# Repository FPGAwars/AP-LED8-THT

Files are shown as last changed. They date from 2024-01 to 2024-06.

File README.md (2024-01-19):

# AP-LED8-THT
Alhambra Peripheral board with 8 through-hole LEDs

It is a tiny board with eight 3mm though-hole LEDs for connecting to the Alhambra-II FPGA board.  
This board is also used as a reference for teaching students how to design their first PCB (so, it is a kind of "hello world" hardware)

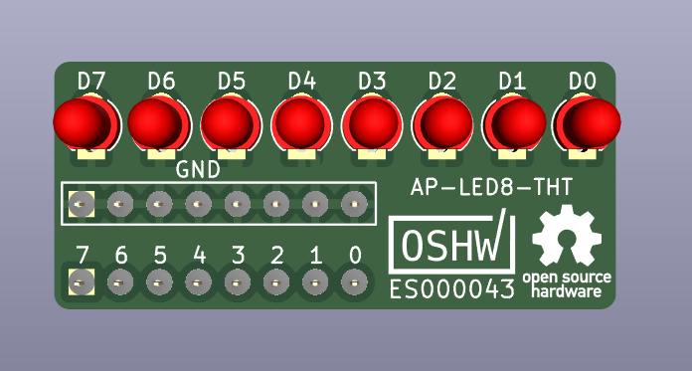
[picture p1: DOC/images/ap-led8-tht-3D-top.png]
Top view
  
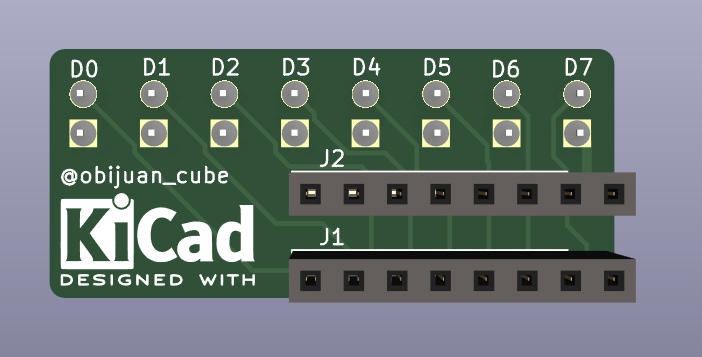
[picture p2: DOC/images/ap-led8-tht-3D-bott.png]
Bottom view
  
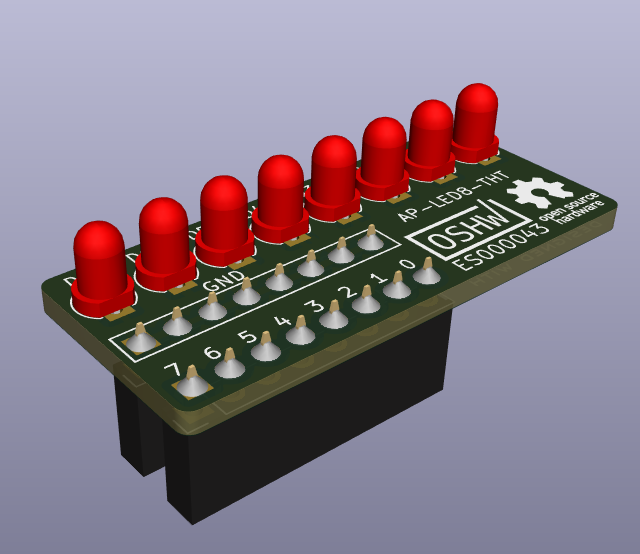
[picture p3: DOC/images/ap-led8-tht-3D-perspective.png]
Perspective View
  

## Connection to Alhambra II Board

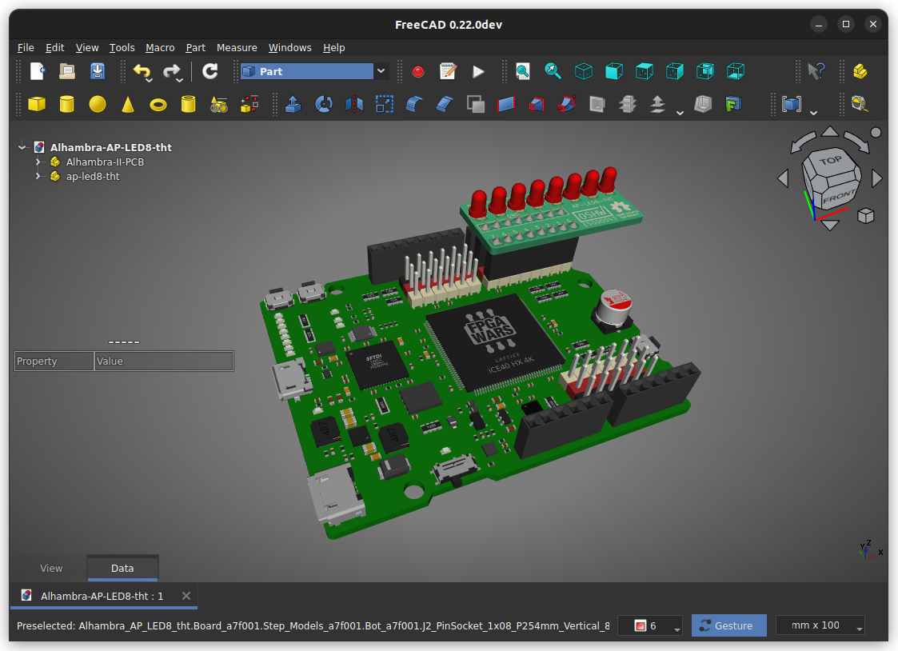
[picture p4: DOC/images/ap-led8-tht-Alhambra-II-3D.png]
Alhambra-II+AP-LED8-THT


## Certification mark

This board is Opensource hardware, certified by the [OSHWA](https://www.oshwa.org/)

* Certification ID: [ES000043](https://certification.oshwa.org/es000043.html)  

* Certification mark:



## License

Documentation licensed under the [Creative Commons Attribution Share Alike 4.0 International License](https://creativecommons.org/licenses/by-sa/4.0/)  


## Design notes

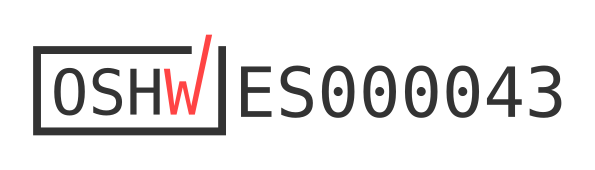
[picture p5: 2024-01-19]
DOC/OSHWA-certification/certification-mark-ES000043-wide.png

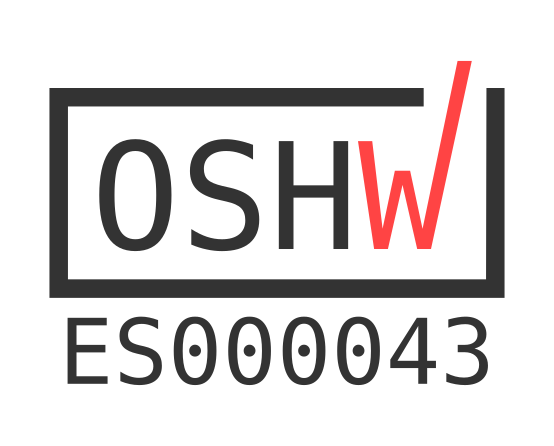
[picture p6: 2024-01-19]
DOC/OSHWA-certification/Certification-mark-ES000043-stacked.png

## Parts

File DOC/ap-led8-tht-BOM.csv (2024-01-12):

Source: | /home/obijuan/Develop/AP-LED8-THT/ap-led8-tht.kicad_sch
Date: | vie 12 ene 2024 10:51:23
Tool: | Eeschema 7.0.10-7.0.10~ubuntu22.04.1
Generator: | /usr/share/kicad/plugins/bom_csv_grouped_by_value.py
Component Count: | 10
Collated Components:
Item | Qty | Reference(s) | Value | LibPart | Footprint | Datasheet | DNP
1 | 8 | D0, D1, D2, D3, D4, D5, D6, D7 | LED | Device:LED | Monolito:LED_THT__LED_D3.0mm | ~
2 | 2 | J1, J2 | Conn_01x08_Socket | Connector:Conn_01x08_Socket | Monolito:PinSocket_1x08_P2.54mm_Vertical | ~

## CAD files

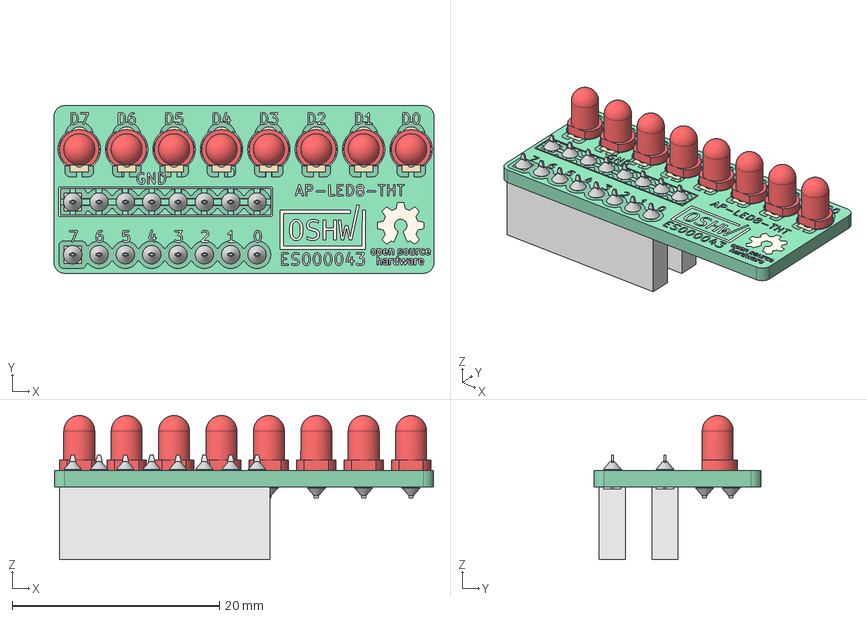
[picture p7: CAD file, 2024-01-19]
DOC/3D/AP-LED8-THT.FCStd
36.6 x 16.2 x 13.9 mm
Pcb_a7f0
topPads_a7f0
topTracks_a7f0
topZones_a7f0
botPads_a7f0
botTracks_a7f0
botSilks_889f
topSilks_854b001
LED-head x 8
Pin-master x 8
Pin-master001 x 8
Solder x 8
Solder001 x 8
J2_PinSocket_1x08_P254mm_Vertical_845b5e165b4b x 2
Solder002 x 2
Solder003 x 2
Solder004 x 2
Solder005 x 2
Solder006 x 2
Solder007 x 2
Solder008 x 2
Solder009 x 2

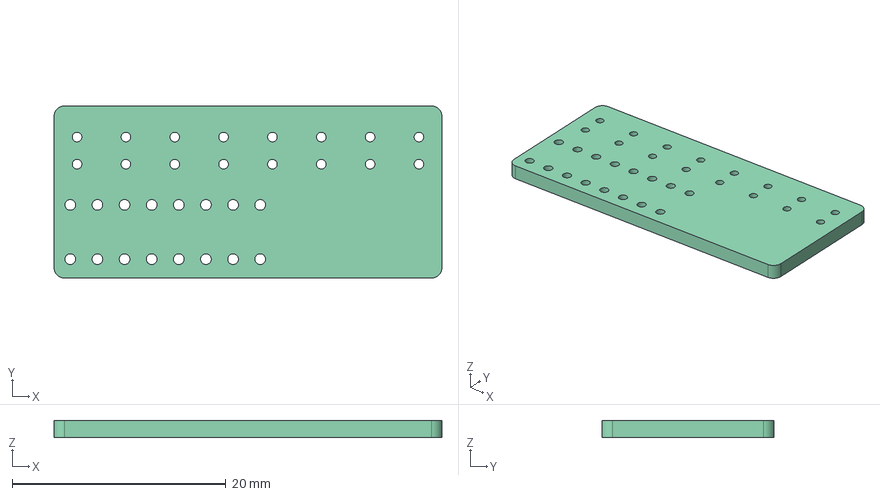
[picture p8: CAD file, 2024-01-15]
edge.FCStd
36.3 x 16.1 x 1.60 mm

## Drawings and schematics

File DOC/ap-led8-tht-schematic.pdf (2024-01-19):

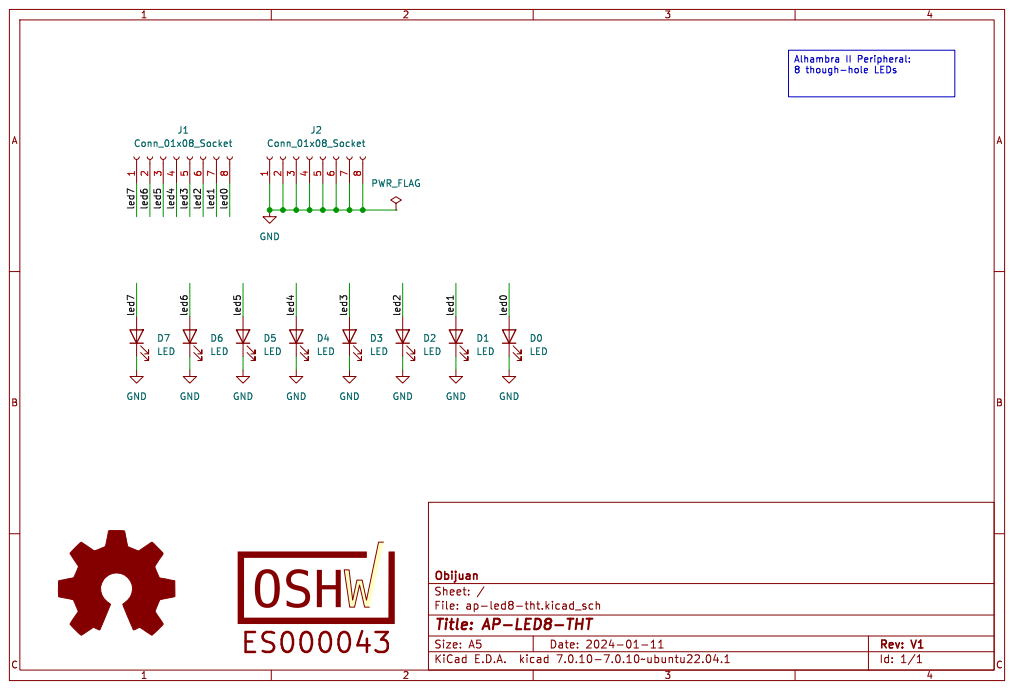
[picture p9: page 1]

File: ap-led8-tht.kicad_sch Sheet: / Obijuan D5

Id: 1/1 Title: AP-LED8-THT

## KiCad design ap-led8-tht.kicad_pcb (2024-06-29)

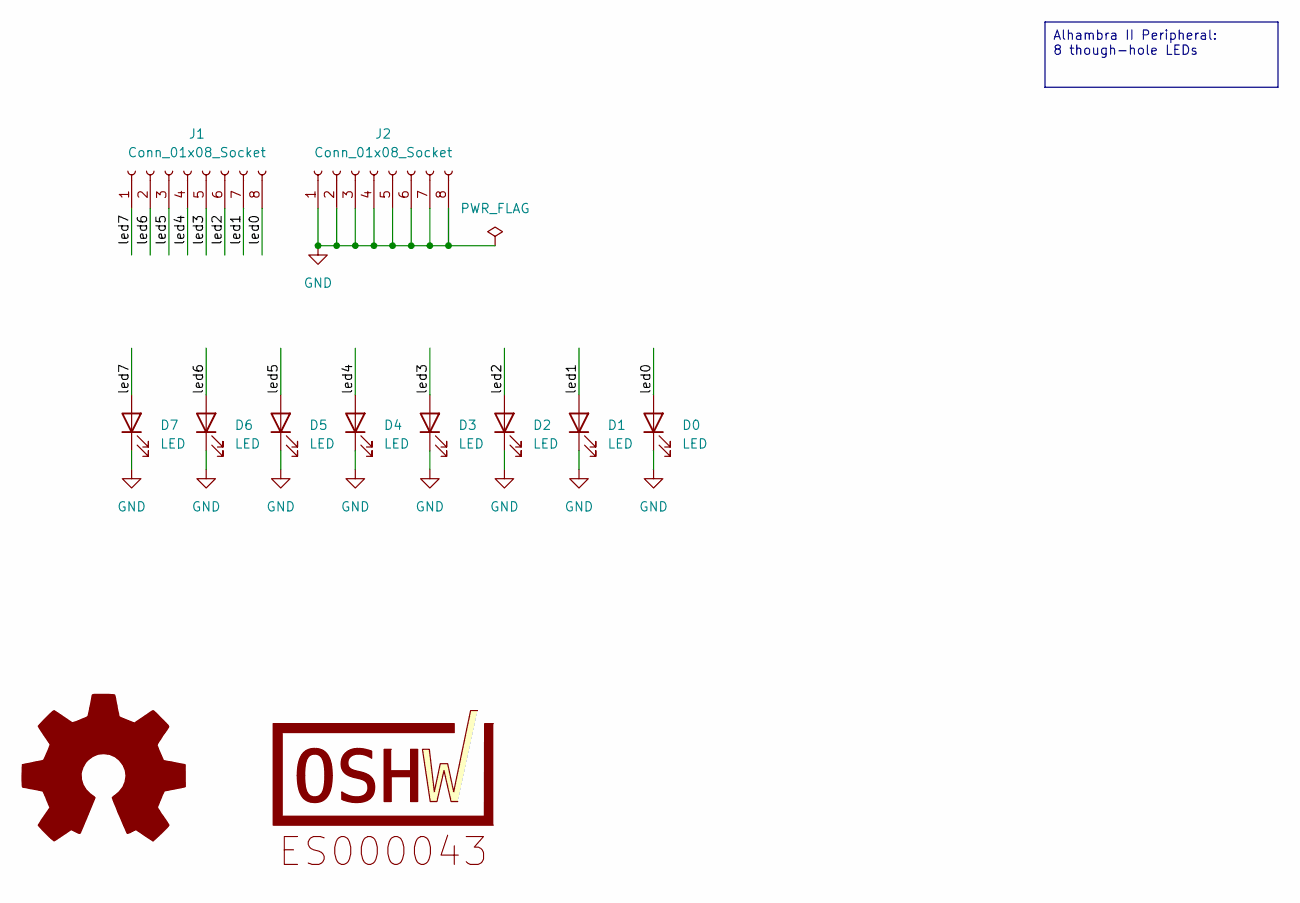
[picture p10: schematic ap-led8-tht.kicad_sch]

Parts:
D0, D1, D2, D3, D4, D5, D6, D7: LED; LED_THT__LED_D3.0mm
J1, J2: Conn_01x08_Socket; PinSocket_1x08_P2.54mm_Vertical
LOGO2: (no value)

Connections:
/led0: D0.2 (A), J1.8
/led1: D1.2 (A), J1.7
/led2: D2.2 (A), J1.6
/led3: D3.2 (A), J1.5
/led4: D4.2 (A), J1.4
/led5: D5.2 (A), J1.3
/led6: D6.2 (A), J1.2
/led7: D7.2 (A), J1.1
GND: D0.1 (K), D1.1 (K), D2.1 (K), D3.1 (K), D4.1 (K), D5.1 (K), D6.1 (K), D7.1 (K), J2.1, J2.2, J2.3, J2.4, J2.5, J2.6, J2.7, J2.8

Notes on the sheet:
Alhambra II Peripheral: 8 though-hole LEDs

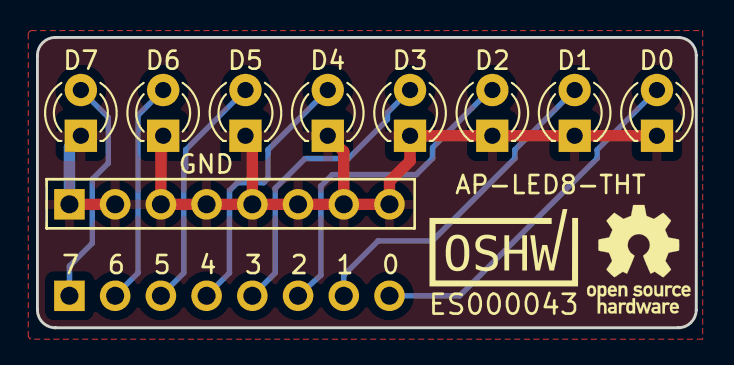
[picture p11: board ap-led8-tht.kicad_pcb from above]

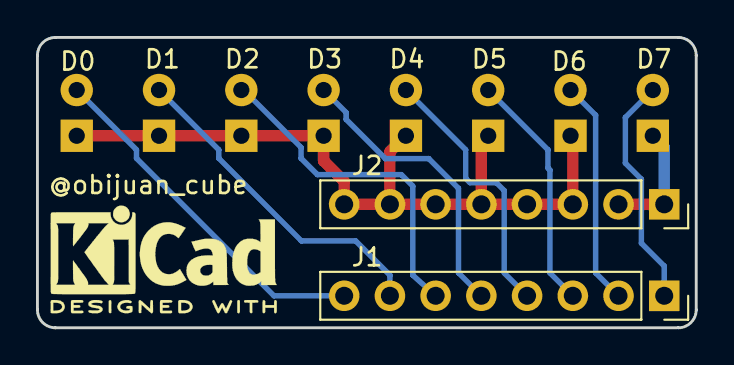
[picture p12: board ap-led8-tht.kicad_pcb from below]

Board: 2 copper layers, 36.6 x 16.1 mm, 10 parts (2 on the bottom side), 9 nets.

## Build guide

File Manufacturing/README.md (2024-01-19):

# Manufacturing

## 1st Batch

* Manufacturer: pcbway.com
* Quantity: 20 boards
* Price: 50€ aprox, including delivery (from china to Madrid, Spain)
* Date: 2024-Jan-19 (order placed)
* File sent: ap-led8-tht.kicad_pcb.zip. File automatically created with the Kicad pcbway plugin

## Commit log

2024-01-11 add initial design
    [ap-led8-tht.kicad_pcb, ap-led8-tht.kicad_sch]
2024-01-11 add monolito footprints and 3dshapes
2024-01-11 Initial PCB
    [ap-led8-tht.kicad_pcb, ap-led8-tht.kicad_sch]
2024-01-11 add top and bottom silkscreens
    [ap-led8-tht.kicad_pcb]
2024-01-12 LEDs moved to make the board less in width
    [ap-led8-tht.kicad_pcb]
2024-01-12 pcb: update silkscreen
    [ap-led8-tht.kicad_pcb]
2024-01-12 add license to board and documentation
2024-01-12 Add bom and schematic (in pdf and svg)
    [ap-led8-tht-BOM.csv]
2024-01-12 Add interactive bom (ibom)
2024-01-12 add 3D board images for the documentation
2024-01-12 Add Freecad 3D models
    [AP-LED8-THT.FCStd]
2024-01-12 update pcb
    [ap-led8-tht.kicad_pcb]
2024-01-12 update pcb: rounded corners
    [ap-led8-tht.kicad_pcb]
2024-01-12 add Freecad edge
    [edge.FCStd]
2024-01-15 PCB: add front GND zone
    [ap-led8-tht.kicad_pcb]
2024-01-15 PCB: fixed DRC warnings
    [ap-led8-tht.kicad_pcb, edge.FCStd]
2024-01-15 update Freecad edge
    [edge.FCStd]
2024-01-15 PCB: New GND zone
    [ap-led8-tht.kicad_pcb]
2024-01-15 update Freecad 3D
    [AP-LED8-THT.FCStd, ap-led8-tht.kicad_pcb]
2024-01-19 add certification mark footprint
    [ap-led8-tht.kicad_pcb]
2024-01-19 update freecad 3D model (new top silkscreen)
    [AP-LED8-THT.FCStd]
2024-01-19 add ap-led-tht step
2024-01-19 add Alhambra-II with ap-led-tht 3D Freecad
2024-01-19 schematic: add oshw logo and certification mark
    [ap-led8-tht.kicad_sch]
2024-01-19 plot schematic to pdf and svg
2024-06-29 update files to Kicad 8
    [ap-led8-tht.kicad_pcb, ap-led8-tht.kicad_sch]
